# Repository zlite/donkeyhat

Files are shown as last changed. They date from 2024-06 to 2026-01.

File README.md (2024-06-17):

This is the repo for the new Donkeycar RC hat (aka Donkeyhat) for the Raspberry Pi. It has a Waveshare RP2040-zero microprocessor running CircuitPython 9.x and has the following functions:

* Read three channels of RC input from a standard RC receiver
* Control two servo channels (steering and throttle)
* Communicates with the RaspberryPi via hardware serial/UART
* Display data on an OLED screen (controlled by the Raspberry Pi via I2C)
* Reads two wheel/shaft encoders, and can handle both single channel and quadrature encoders
* Blinks a Neopixel LED to show normal operation

Instructructions:
* Copy the CircuitPython firmware to the RP2040 following these instructions: https://circuitpython.org/board/waveshare_rp2040_zero/
* Copy the required Neopixel library files to the "lib" directory of your RP2040 as instructed here: https://learn.adafruit.com/circuitpython-essentials/circuitpython-neopixel
* Copy the `code.py` file to the root for the RP2040 (CircuitPython always runs code.py at startup)
* Use the Mu Editor for modifying the code: https://codewith.mu/

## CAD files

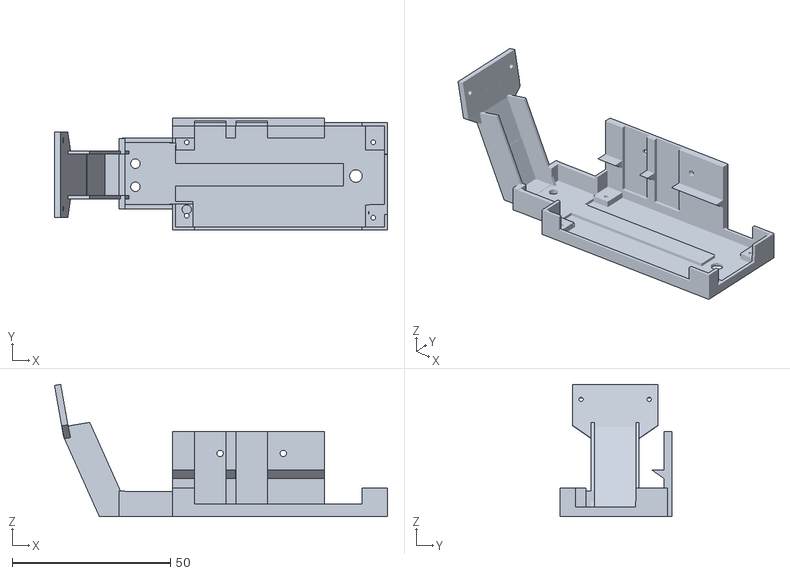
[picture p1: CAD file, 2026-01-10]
Mini RC hat mount.stl
105.4 x 35.5 x 41.8

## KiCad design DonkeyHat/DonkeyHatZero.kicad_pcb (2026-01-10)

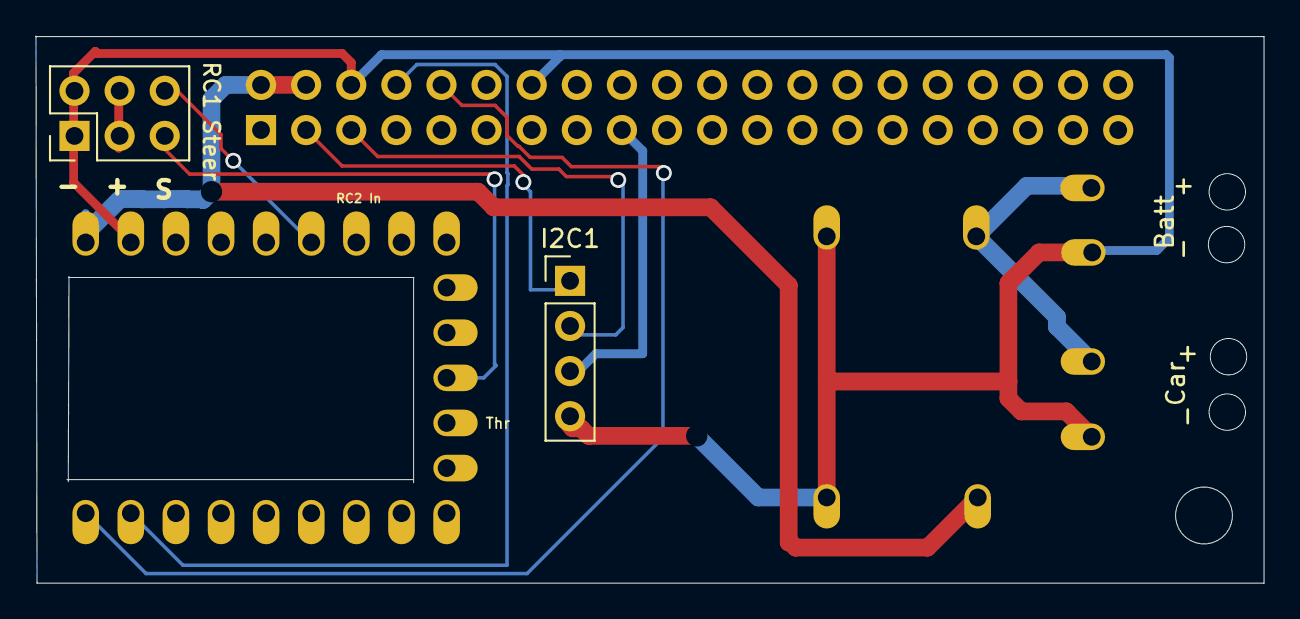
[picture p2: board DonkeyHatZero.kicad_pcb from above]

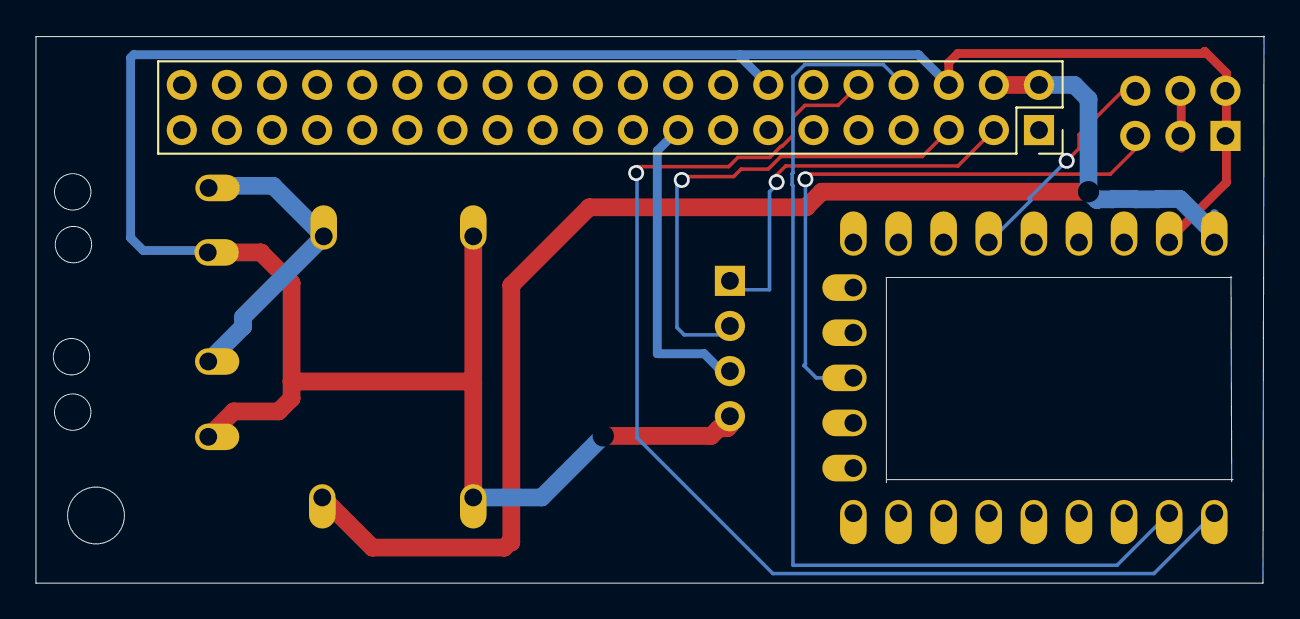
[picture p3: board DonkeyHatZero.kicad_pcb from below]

Board: 2 copper layers, 69.1 x 30.8 mm, 4 parts (2 on the bottom side), 10 nets.

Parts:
I2C1: Conn_01x04_Pin; PinHeader_1x04_P2.54mm_Vertical
J1: GPIO; PinSocket_2x20_P2.54mm_Vertical
J4: Conn_02x03_Top_Bottom; PinHeader_2x03_P2.54mm_Vertical
U2: rp2040-zero; rp2040-zero-tht

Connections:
+3V3: I2C1.3, J1.1, J1.17
+5V: J1.2, J1.4, U2.23 (5V)
/GPIO2/SDA1: I2C1.1, J1.3
/GPIO3/SCL1: I2C1.2, J1.5
GND: I2C1.4, J1.6, J1.14, J4.1, J4.4, U2.22 (GND)
unnamed: J4.2, J4.5
RCin1: J4.6, U2.18 (27)
Rpi Rx: J1.10, U2.1 (0)
Rpi Tx: J1.8, U2.2 (1)
Steer: J4.3, U2.12 (11)

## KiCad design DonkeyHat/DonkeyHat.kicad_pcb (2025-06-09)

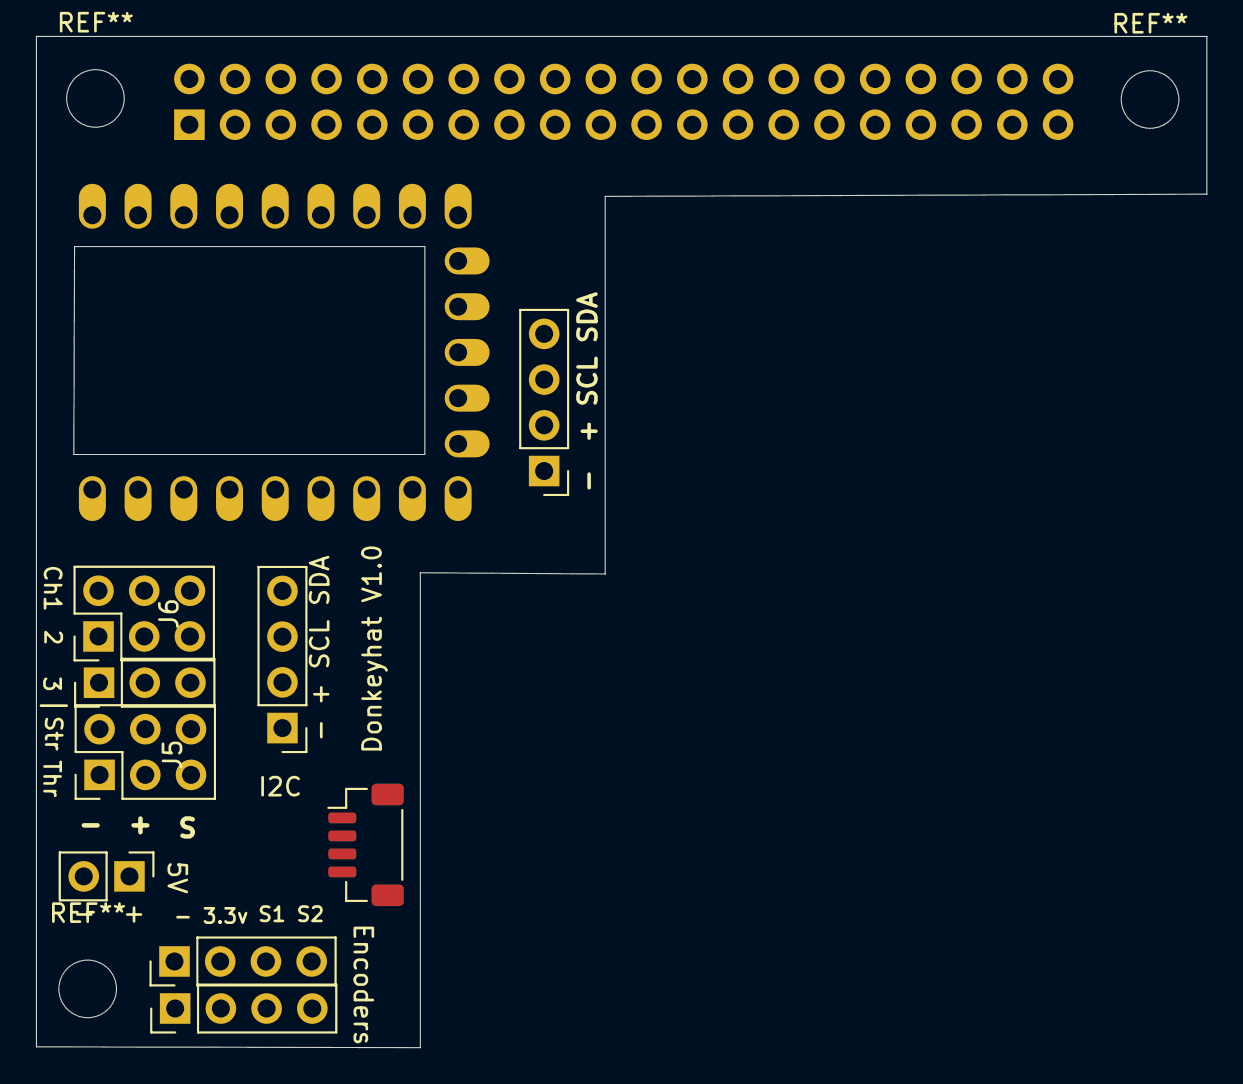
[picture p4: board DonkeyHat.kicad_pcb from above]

Board: 2 copper layers, 65.0 x 56.2 mm, 11 parts (1 on the bottom side), 17 nets, no tracks yet.

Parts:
5V1: Conn_01x02_Pin; PinHeader_1x02_P2.54mm_Vertical
I2C1: Conn_01x04_Pin; PinHeader_1x04_P2.54mm_Vertical
J1: GPIO; PinSocket_2x20_P2.54mm_Vertical
J2: Encoder 2; PinHeader_1x04_P2.54mm_Vertical
J3: Encoder 1; PinHeader_1x04_P2.54mm_Vertical
J4: I2C; JST_SH_BM04B-SRSS-TB_1x04-1MP_P1.00mm_Vertical
J5, J6: Conn_02x03_Odd_Even; PinHeader_2x03_P2.54mm_Vertical
OLED1: Conn_01x04_Pin; PinHeader_1x04_P2.54mm_Vertical
Throttle1: Conn_01x03_Pin; PinHeader_1x03_P2.54mm_Vertical
U2: rp2040-zero; rp2040-zero-tht

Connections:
+3V3: I2C1.2, J1.1, J1.17, J2.2, J3.2, J4.3, OLED1.2
+5V: 5V1.1, J1.2, J1.4, J6.3, J6.4, Throttle1.2, U2.23 (5V)
/GPIO2/SDA1: I2C1.4, J1.3, J4.2, OLED1.4
/GPIO3/SCL1: I2C1.3, J1.5, J4.1, OLED1.3
Batt: J5.3, J5.4
Enc1A: J3.3, U2.8 (7)
Enc1B: J3.4, U2.9 (8)
Enc2A: J2.3, U2.13 (12)
Enc2B: J2.4, U2.14 (13)
GND: 5V1.2, I2C1.1, J1.6, J1.9, J1.14, J1.20, J1.25, J1.30, J1.34, J1.39, J2.1, J3.1, J4.4, J5.1, J5.2, J6.1, J6.2, OLED1.1, Throttle1.1, U2.22 (GND)
RCin1: J6.6, U2.18 (27)
RCin2: J6.5, U2.17 (26)
RCin3: Throttle1.3, U2.20 (29)
Rpi Rx: J1.10, U2.1 (0)
Rpi Tx: J1.8, U2.2 (1)
Steer: J5.6, U2.12 (11)
Throttle: J5.5, U2.11 (10)

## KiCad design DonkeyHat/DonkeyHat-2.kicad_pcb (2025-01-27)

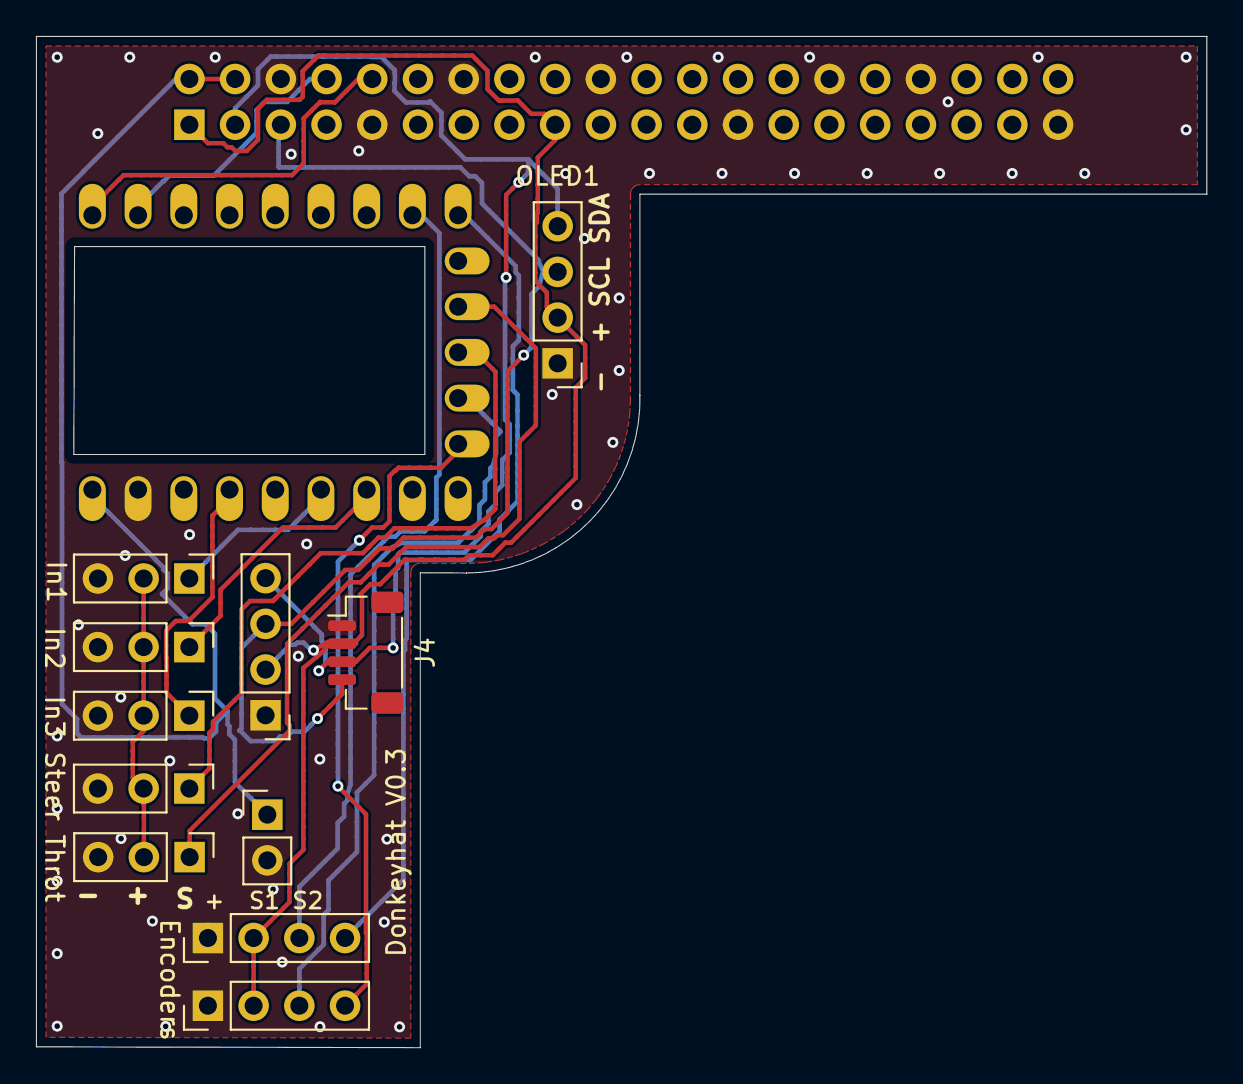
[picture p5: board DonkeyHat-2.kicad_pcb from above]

Board: 2 copper layers, 65.0 x 56.2 mm, 13 parts (1 on the bottom side), 17 nets.

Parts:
5V1: Conn_01x02_Pin; PinHeader_1x02_P2.54mm_Vertical
I2C1: Conn_01x04_Pin; PinHeader_1x04_P2.54mm_Vertical
In1: RC 1; PinHeader_1x03_P2.54mm_Vertical
In2, In3: Conn_01x03_Pin; PinHeader_1x03_P2.54mm_Vertical
J1: GPIO; PinSocket_2x20_P2.54mm_Vertical
J2: Encoder 2; PinHeader_1x04_P2.54mm_Vertical
J3: Encoder 1; PinHeader_1x04_P2.54mm_Vertical
J4: B4B-PH-K-S_LF__SN_; JST_SH_BM04B-SRSS-TB_1x04-1MP_P1.00mm_Vertical
OLED1: Conn_01x04_Pin; PinHeader_1x04_P2.54mm_Vertical
St1: Conn_01x03_Pin; PinHeader_1x03_P2.54mm_Vertical
Thr1: Conn_01x03_Pin; PinHeader_1x03_P2.54mm_Vertical
U2: rp2040-zero; rp2040-zero-tht

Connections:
+3V3: I2C1.2, J1.1, J1.17, J2.2, J3.2, J4.2, OLED1.2
+5V: 5V1.1, J1.2, J1.4, U2.23 (5V)
+BATT: In1.2, In2.2, In3.2, St1.2, Thr1.2
/GPIO2/SDA1: I2C1.4, J1.3, J4.3, OLED1.4
/GPIO3/SCL1: I2C1.3, J1.5, J4.4, OLED1.3
/GPIO14/TXD0: J1.8, U2.2 (1)
/GPIO15/RXD0: J1.10, U2.1 (0)
Enc1A: J3.3, U2.8 (7)
Enc1B: J3.4, U2.9 (8)
Enc2A: J2.3, U2.13 (12)
Enc2B: J2.4, U2.14 (13)
GND: 5V1.2, I2C1.1, In1.3, In2.3, In3.3, J1.6, J1.9, J1.14, J1.20, J1.25, J1.30, J1.34, J1.39, J2.1, J3.1, J4.1, OLED1.1, St1.3, Thr1.3, U2.22 (GND)
unnamed: In1.1, U2.20 (29)
unnamed: In2.1, U2.17 (26)
unnamed: In3.1, U2.18 (27)
unnamed: St1.1, U2.11 (10)
unnamed: Thr1.1, U2.12 (11)

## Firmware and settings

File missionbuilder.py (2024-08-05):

import sys
import csv
import os
import math
import json
from PySide6.QtWidgets import QApplication, QMainWindow, QVBoxLayout, QHBoxLayout, QWidget, QPushButton, QListWidget, QListWidgetItem, QDoubleSpinBox, QLabel, QFileDialog, QCheckBox, QMessageBox
from PySide6.QtWebEngineWidgets import QWebEngineView
from PySide6.QtWebEngineCore import QWebEnginePage, QWebEngineProfile, QWebEngineSettings
from PySide6.QtCore import QUrl, QObject, Slot, Qt
from PySide6.QtWebChannel import QWebChannel
from PySide6.QtCore import QTimer

class CustomWebEnginePage(QWebEnginePage):
    def javaScriptConsoleMessage(self, level, message, lineNumber, sourceID):
        print(f"JS Console ({level}): {message} [line {lineNumber}]")

class Bridge(QObject):
    @Slot(float, float)
    def addWaypoint(self, lat, lng):
        window.add_waypoint(lat, lng, is_relative=window.relative_checkbox.isChecked())

    @Slot(int, float, float)
    def updateWaypoint(self, index, lat, lng):
        window.update_waypoint(index, lat, lng)

class WaypointWidget(QWidget):
    def __init__(self, number, lat, lng, throttle=0.2, parent=None):
        super().__init__(parent)
        self.layout = QHBoxLayout(self)
        self.layout.setContentsMargins(0, 0, 0, 0)
        self.number_label = QLabel(f"{number}.")
        self.coords_label = QLabel()
        self.throttle_spinbox = QDoubleSpinBox()
        self.throttle_spinbox.setRange(0, 1)
        self.throttle_spinbox.setSingleStep(0.1)
        self.throttle_spinbox.setValue(throttle)
        self.throttle_spinbox.setDecimals(2)
        self.throttle_spinbox.setFixedWidth(90)
        self.throttle_spinbox.setAlignment(Qt.AlignRight)

        self.layout.addWidget(self.number_label)
        self.layout.addWidget(self.coords_label, 1)
        self.layout.addWidget(QLabel("Throttle:"))
        self.layout.addWidget(self.throttle_spinbox)

        self.abs_lat = lat
        self.abs_lng = lng
        self.rel_lat = 0
        self.rel_lng = 0
        self.is_relative = False
        self.update_coords(lat, lng)

    def update_number(self, number):
        self.number_label.setText(f"{number}.")

    def update_coords(self, lat, lng, relative=False, home_lat=None, home_lng=None):
        self.is_relative = relative
        if relative and home_lat is not None and home_lng is not None:
            self.rel_lat = lat  # lat is already in meters
            self.rel_lng = lng  # lng is already in meters
            self.abs_lat, self.abs_lng = self.meters_to_lat_lon(lat, lng, home_lat, home_lng)
            self.coords_label.setText(f"ΔLat: {lat:.2f}m, ΔLng: {lng:.2f}m")
        else:
            self.abs_lat = lat
            self.abs_lng = lng
            self.rel_lat = 0
            self.rel_lng = 0
            self.coords_label.setText(f"Lat: {lat:.6f}, Lng: {lng:.6f}")

    @staticmethod
    def meters_to_lat_lon(dlat_m, dlng_m, home_lat, home_lng):
        dlat = dlat_m / 111139
        dlng = dlng_m / (111139 * math.cos(math.radians(home_lat)))
        return home_lat + dlat, home_lng + dlng

    def get_data(self):
        return {
            "abs_lat": self.abs_lat,
            "abs_lng": self.abs_lng,
            "rel_lat": self.rel_lat,
            "rel_lng": self.rel_lng,
            "is_relative": self.is_relative,
            "throttle": self.throttle_spinbox.value()
        }

class WaypointCreator(QMainWindow):
    def __init__(self):
        super().__init__()
        self.setWindowTitle("Donkeycar Waypoint Creator")
        self.setGeometry(100, 100, 1200, 600)

        main_layout = QHBoxLayout()

        self.map_widget = QWebEngineView()
        main_layout.addWidget(self.map_widget, 7)

        sidebar_layout = QVBoxLayout()
        
        self.waypoint_list = QListWidget()
        self.waypoint_list.setDragDropMode(QListWidget.InternalMove)
        self.waypoint_list.model().rowsMoved.connect(self.on_waypoints_reordered)
        sidebar_layout.addWidget(self.waypoint_list)

        delete_button = QPushButton("Delete Selected Waypoint")
        delete_button.clicked.connect(self.delete_selected_waypoint)
        sidebar_layout.addWidget(delete_button)

        save_button = QPushButton("Save Waypoints")
        save_button.clicked.connect(self.save_waypoints)
        sidebar_layout.addWidget(save_button)

        load_button = QPushButton("Load Waypoints")
        load_button.clicked.connect(self.load_waypoints)
        sidebar_layout.addWidget(load_button)

        set_home_button = QPushButton("Set Home to Map Center")
        set_home_button.clicked.connect(self.set_home_to_map_center)
        sidebar_layout.addWidget(set_home_button)

        self.relative_checkbox = QCheckBox("Use Relative Coordinates")
        self.relative_checkbox.stateChanged.connect(self.toggle_relative_coordinates)
        sidebar_layout.addWidget(self.relative_checkbox)

        main_layout.addLayout(sidebar_layout, 3)

        central_widget = QWidget()
        central_widget.setLayout(main_layout)
        self.setCentralWidget(central_widget)

        self.init_map()
        self.home_lat = None
        self.home_lng = None
        self.waypoints = []
        self.is_relative = False

    def delay_init(self):
        QTimer.singleShot(1000, self.post_map_init)

    def post_map_init(self):
        # Any initialization that needs to happen after the map is loaded
        print("Map should be loaded now")
        # You can add any necessary initialization here

    def init_map(self):
        self.channel = QWebChannel()
        self.bridge = Bridge()
        self.channel.registerObject('bridge', self.bridge)

        profile = QWebEngineProfile.defaultProfile()
        settings = profile.settings()
        settings.setAttribute(QWebEngineSettings.LocalContentCanAccessRemoteUrls, True)
        settings.setAttribute(QWebEngineSettings.LocalContentCanAccessFileUrls, True)
        settings.setAttribute(QWebEngineSettings.AllowGeolocationOnInsecureOrigins, True)
        settings.setAttribute(QWebEngineSettings.AllowRunningInsecureContent, True)

        page = CustomWebEnginePage(profile, self.map_widget)
        page.setWebChannel(self.channel)

        page.featurePermissionRequested.connect(self.handlePermissionRequest)

        self.map_widget.setPage(page)

        html_path = os.path.join(os.path.dirname(os.path.abspath(__file__)), "map_template.html")
        self.map_widget.setUrl(QUrl.fromLocalFile(html_path))
 
    def meters_to_lat_lon(self, dlat_m, dlng_m, home_lat, home_lng):
        dlat = dlat_m / 111139
        dlng = dlng_m / (111139 * math.cos(math.radians(home_lat)))
        return home_lat + dlat, home_lng + dlng

    def lat_lon_to_meters(self, lat, lng, home_lat, home_lng):
        dlat_m = (lat - home_lat) * 111139
        dlng_m = (lng - home_lng) * 111139 * math.cos(math.radians(home_lat))
        return dlat_m, dlng_m

    def handlePermissionRequest(self, url, feature):
        if feature == QWebEnginePage.Geolocation:
            self.map_widget.page().setFeaturePermission(url, feature, QWebEnginePage.PermissionGrantedByUser)
        else:
            self.map_widget.page().setFeaturePermission(url, feature, QWebEnginePage.PermissionDeniedByUser)

    def add_waypoint(self, lat, lng, throttle=0.2, is_relative=False):
        if self.waypoint_list.count() == 0:
            self.home_lat, self.home_lng = lat, lng
            is_relative = False
        
        waypoint_widget = WaypointWidget(self.waypoint_list.count() + 1, lat, lng, throttle)
        
        if is_relative:
            rel_lat = (lat - self.home_lat) * 111139
            rel_lng = (lng - self.home_lng) * 111139 * math.cos(math.radians(self.home_lat))
            waypoint_widget.update_coords(rel_lat, rel_lng, relative=True, home_lat=self.home_lat, home_lng=self.home_lng)
        else:
            waypoint_widget.update_coords(lat, lng, relative=False)
        
        item = QListWidgetItem(self.waypoint_list)
        item.setSizeHint(waypoint_widget.sizeHint())
        self.waypoint_list.addItem(item)
        self.waypoint_list.setItemWidget(item, waypoint_widget)
        
        self.update_map_markers()

    def update_waypoint(self, index, lat, lng):
        item = self.waypoint_list.item(index)
        waypoint_widget = self.waypoint_list.itemWidget(item)
        
        if index == 0:
            # First waypoint is always absolute
            waypoint_widget.update_coords(lat, lng, relative=False)
            self.home_lat, self.home_lng = lat, lng
        elif self.relative_checkbox.isChecked():
            # Convert the new absolute position to relative
            dlat_m, dlng_m = self.lat_lon_to_meters(lat, lng, self.home_lat, self.home_lng)
            waypoint_widget.update_coords(dlat_m, dlng_m, relative=True, home_lat=self.home_lat, home_lng=self.home_lng)
        else:
            waypoint_widget.update_coords(lat, lng, relative=False)
        
        self.update_waypoint_display()
        self.update_map_markers()
        print(f"Waypoint {index + 1} updated: Lat: {lat:.6f}, Lng: {lng:.6f}")

    def on_waypoints_reordered(self):
        for i in range(self.waypoint_list.count()):
            item = self.waypoint_list.item(i)
            waypoint_widget = self.waypoint_list.itemWidget(item)
            waypoint_widget.update_number(i + 1)
        self.update_map_markers()

    def delete_selected_waypoint(self):
        selected_items = self.waypoint_list.selectedItems()
        if selected_items:
            for item in selected_items:
                self.waypoint_list.takeItem(self.waypoint_list.row(item))
            self.on_waypoints_reordered()
            self.update_map_markers()

    def update_map_markers(self):
        waypoints = [self.waypoint_list.itemWidget(self.waypoint_list.item(i)).get_data() 
                    for i in range(self.waypoint_list.count())]
        map_waypoints = []
        for wp in waypoints:
            map_waypoints.append({
                "lat": wp['abs_lat'],
                "lng": wp['abs_lng'],
                "throttle": float(wp['throttle'])
            })
        self.map_widget.page().runJavaScript(f"updateMarkers({json.dumps(map_waypoints)});")

    def save_waypoints(self):
        options = QFileDialog.Options()
        options |= QFileDialog.DontUseNativeDialog
        file_name, _ = QFileDialog.getSaveFileName(self, "Save Waypoints", "donkey_path.csv", "CSV Files (*.csv)", options=options)
        if file_name:
            waypoints = [self.waypoint_list.itemWidget(self.waypoint_list.item(i)).get_data() 
                        for i in range(self.waypoint_list.count())]
            with open(file_name, 'w', newline='') as f:
                writer = csv.writer(f)
                for i, wp in enumerate(waypoints):
                    if i == 0 or not self.relative_checkbox.isChecked():
                        # Absolute coordinates: 10 decimal places
                        lat = f"{wp['abs_lat']:.10f}"
                        lng = f"{wp['abs_lng']:.10f}"
                    else:
                        # Relative coordinates: 2 decimal places
                        lat = f"{wp['rel_lat']:.2f}"
                        lng = f"{wp['rel_lng']:.2f}"
                    writer.writerow([lat, lng, f"{wp['throttle']:.2f}"])
            print(f"Waypoints saved to {file_name}")

    def load_waypoints(self):
        options = QFileDialog.Options()
        options |= QFileDialog.DontUseNativeDialog
        file_name, _ = QFileDialog.getOpenFileName(self, "Load Waypoints", "", "CSV Files (*.csv)", options=options)
        if file_name:
            self.waypoint_list.clear()
            self.home_lat = None
            self.home_lng = None
            
            self.waypoints = []
            self.is_relative = False
            with open(file_name, 'r') as f:
                reader = csv.reader(f)
                for i, row in enumerate(reader):
                    if len(row) == 3:
                        lat, lng, throttle = row
                        if i == 0:
                            # First waypoint is always absolute
                            lat, lng = float(lat), float(lng)
                            self.home_lat, self.home_lng = lat, lng
                        elif '.' in lat and len(lat.split('.')[1]) <= 2:
                            # Relative coordinates have 2 or fewer decimal places
                            self.is_relative = True
                            lat, lng = float(lat), float(lng)
                        else:
                            # Absolute coordinates
                            lat, lng = float(lat), float(lng)
                        throttle = float(throttle)
                        self.waypoints.append((lat, lng, throttle))
            
            self.relative_checkbox.setChecked(self.is_relative)
            self.process_waypoints()
    def set_home_to_map_center(self):
        js_code = """
        (function() {
            var map = getOrInitMap();
            if (map) {
                var center = map.getCenter();
                return JSON.stringify({
                    lat: center.lat,
                    lng: center.lng
                });
            } else {
                console.error("Map not initialized");
                return null;
            }
        })();
        """
        self.map_widget.page().runJavaScript(js_code, 0, self.on_map_center_received)
        print("Requested map center")

    def force_map_center_update(self):
        js_code = "storeMapCenter();"
        self.map_widget.page().runJavaScript(js_code)

    def on_map_center_received(self, result):
        print(f"Received result: {result}")
        try:
            if not result:
                raise ValueError("Received empty result from JavaScript")

            center = json.loads(result)

            if 'lat' not in center or 'lng' not in center:
                raise KeyError(f"Expected 'lat' and 'lng' keys, but got: {center.keys()}")

            new_home_lat, new_home_lng = float(center['lat']), float(center['lng'])
            print(f"New home set to: Lat: {new_home_lat:.6f}, Lng: {new_home_lng:.6f}")
            
            self.set_home_and_redraw_waypoints(new_home_lat, new_home_lng)
                
        except json.JSONDecodeError as e:
            print(f"Error decoding JSON: {e}")
        except KeyError as e:
            print(f"Error accessing data: {e}")
        except ValueError as e:
            print(f"Value error: {e}")
        except Exception as e:
            print(f"Unexpected error: {e}")
        finally:
            print(f"Raw received data: {result}")

    def on_map_center_received_fallback(self, result):
        print(f"Fallback received result: {result}")
        try:
            center = json.loads(result)
            new_home_lat, new_home_lng = float(center['lat']), float(center['lng'])
            print(f"New home set to: Lat: {new_home_lat:.6f}, Lng: {new_home_lng:.6f}")
            self.set_home_and_redraw_waypoints(new_home_lat, new_home_lng)
        except Exception as e:
            print(f"Error in fallback method: {e}")

    def set_home_and_redraw_waypoints(self, new_home_lat, new_home_lng):
        if self.waypoint_list.count() == 0:
            return

        old_home_lat, old_home_lng = self.home_lat, self.home_lng
        self.home_lat, self.home_lng = new_home_lat, new_home_lng

        # Update the first waypoint (home)
        first_item = self.waypoint_list.item(0)
        first_waypoint = self.waypoint_list.itemWidget(first_item)
        first_waypoint.update_coords(new_home_lat, new_home_lng, relative=False)

        # Update all other waypoints
        for i in range(1, self.waypoint_list.count()):
            item = self.waypoint_list.item(i)
            waypoint_widget = self.waypoint_list.itemWidget(item)
            data = waypoint_widget.get_data()
            
            if self.relative_checkbox.isChecked():
                # Keep the relative offset
                waypoint_widget.update_coords(data['rel_lat'], data['rel_lng'], relative=True, home_lat=self.home_lat, home_lng=self.home_lng)
            else:
                # Adjust absolute position
                dlat = data['abs_lat'] - old_home_lat
                dlng = data['abs_lng'] - old_home_lng
                new_lat = new_home_lat + dlat
                new_lng = new_home_lng + dlng
                waypoint_widget.update_coords(new_lat, new_lng, relative=False)

        self.update_waypoint_display()
        self.update_map_markers()
        print(f"Waypoints redrawn with new home location: Lat: {self.home_lat:.6f}, Lng: {self.home_lng:.6f}")

    def process_waypoints(self):
        if not self.waypoints:
            return

        # Clear existing waypoints
        self.waypoint_list.clear()

        # Process the first waypoint (always absolute)
        first_wp = self.waypoints[0]
        self.add_waypoint(first_wp[0], first_wp[1], first_wp[2], is_relative=False)
        self.home_lat, self.home_lng = first_wp[0], first_wp[1]

        # Process the rest of the waypoints
        for lat, lng, throttle in self.waypoints[1:]:
            if self.is_relative:
                # Convert relative meters to absolute coordinates
                abs_lat = self.home_lat + lat / 111139
                abs_lng = self.home_lng + lng / (111139 * math.cos(math.radians(self.home_lat)))
                self.add_waypoint(abs_lat, abs_lng, throttle, is_relative=True)
            else:
                self.add_waypoint(lat, lng, throttle, is_relative=False)

        self.update_waypoint_display()

    def toggle_relative_coordinates(self):
        is_relative = self.relative_checkbox.isChecked()
        if self.waypoint_list.count() > 0:
            first_wp = self.waypoint_list.itemWidget(self.waypoint_list.item(0)).get_data()
            self.home_lat, self.home_lng = first_wp['abs_lat'], first_wp['abs_lng']

        for i in range(self.waypoint_list.count()):
            item = self.waypoint_list.item(i)
            waypoint_widget = self.waypoint_list.itemWidget(item)
            data = waypoint_widget.get_data()
            
            if i == 0:
                waypoint_widget.update_coords(data['abs_lat'], data['abs_lng'], relative=False)
            else:
                if is_relative:
                    dlat_m, dlng_m = self.lat_lon_to_meters(data['abs_lat'], data['abs_lng'], self.home_lat, self.home_lng)
                    waypoint_widget.update_coords(dlat_m, dlng_m, relative=True, home_lat=self.home_lat, home_lng=self.home_lng)
                else:
                    waypoint_widget.update_coords(data['abs_lat'], data['abs_lng'], relative=False)

        self.update_map_markers()
        print(f"Toggled to {'relative' if is_relative else 'absolute'} coordinates")

    def update_waypoint_display(self):
        relative = self.relative_checkbox.isChecked()
        for i in range(self.waypoint_list.count()):
            item = self.waypoint_list.item(i)
            waypoint_widget = self.waypoint_list.itemWidget(item)
            data = waypoint_widget.get_data()
            if i == 0:
                # First waypoint is always absolute
                waypoint_widget.update_coords(data['abs_lat'], data['abs_lng'], relative=False)
            elif relative:
                waypoint_widget.update_coords(data['rel_lat'], data['rel_lng'], relative=True, home_lat=self.home_lat, home_lng=self.home_lng)
            else:
                waypoint_widget.update_coords(data['abs_lat'], data['abs_lng'], relative=False)
        
        self.update_map_markers()

if __name__ == '__main__':
    app = QApplication(sys.argv)
    window = WaypointCreator()
    window.show()
    sys.exit(app.exec())
    

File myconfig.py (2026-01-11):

"""
CAR CONFIG

This file is read by your car application's manage.py script to change the car
performance.

EXAMPLE
-----------
import dk
cfg = dk.load_config(config_path='~/mycar/config.py')
print(cfg.CAMERA_RESOLUTION)
"""

import os

# ==============================================================================
# 1. HARDWARE CONFIGURATION & I/O
#    (Camera, Drive Train, Sensors, Pins, Display)
# ==============================================================================

# PATHS
CAR_PATH = PACKAGE_PATH = os.path.dirname(os.path.realpath(__file__))
# DATA_PATH = os.path.join(CAR_PATH, 'data')
# MODELS_PATH = os.path.join(CAR_PATH, 'models')

# ------------------------------------------------------------------------------
# CAMERA SETUP
# ------------------------------------------------------------------------------

# Select the camera type.
# 'PICAM': Raspberry Pi Camera (CSI)
# 'WEBCAM': USB Camera
# 'CVCAM': OpenCV Camera (often same as WEBCAM)
# 'CSIC': High-speed CSI camera (e.g. Arducam)
# 'D435': Intel Realsense D435
# 'OAKD': Luxonis OAK-D
# 'MOCK': Simulation/Testing or when using GPS path following
# CAMERA_TYPE = "PICAM"

# The resolution of the input image. Higher resolution needs more processing power.
# IMAGE_W = 160
# IMAGE_H = 120

# The depth of the image. 3 for RGB, 1 for Greyscale.
# IMAGE_DEPTH = 3

# The framerate of the camera. Should generally match DRIVE_LOOP_HZ.
# CAMERA_FRAMERATE = 20

# Flip the image vertically (useful if camera is mounted upside down).
CAMERA_VFLIP = True

# Flip the image horizontally.
# CAMERA_HFLIP = False

# Used for 'WEBCAM' and 'CVCAM' when there is more than one camera connected.
# CAMERA_INDEX = 0

# CSIC Camera: 0=None, 4=Flip Horizontal, 6=Flip Vertical.
# CSIC_CAM_GSTREAMER_FLIP_PARM = 0

# Convert Blue-Green-Red (OpenCV default) to Red-Green-Blue.
# BGR2RGB = False

# Intel Realsense D435 specific settings
# REALSENSE_D435_RGB = True       # True to capture RGB image
# REALSENSE_D435_DEPTH = True     # True to capture depth as image array
# REALSENSE_D435_IMU = False      # True to capture IMU data (D435i only)
# REALSENSE_D435_ID = None        # Serial number of camera or None for auto-detect

# OAK-D Camera specific settings
# OAKD_RGB = True       # True to capture RGB image
# OAKD_DEPTH = True     # True to capture depth as image array
# OAKD_ID = None        # Serial number of camera or None for auto-detect


# ------------------------------------------------------------------------------
# I2C & DISPLAY
# ------------------------------------------------------------------------------

# I2C address of the PCA9685 servo driver (standard is 0x40).
# PCA9685_I2C_ADDR = 0x40

# I2C bus number. None will auto-detect (usually 1 on Pi).
# PCA9685_I2C_BUSNUM = None

# Enable the SSD1306 OLED display (small screen on the car).
USE_SSD1306_128_32 = True

# OLED Rotation: 0 = normal, 1 = 90 deg, 2 = 180 deg, 3 = 270 deg.
# SSD1306_128_32_I2C_ROTATION = 0

# OLED Resolution: 1 = 128x32, 2 = 128x64.
SSD1306_RESOLUTION = 2


# ------------------------------------------------------------------------------
# INPUT DEVICES (JOYSTICK / CONTROLLER)
# ------------------------------------------------------------------------------

# If True, the joystick is enabled by default without needing '--js' flag.
# USE_JOYSTICK_AS_DEFAULT = True

# The maximum throttle output (0.0 to 1.0) allowed by the joystick.
# Useful for limiting speed for beginners.
# JOYSTICK_MAX_THROTTLE = 0.5

# Scalar for steering. 1.0 is normal. <1.0 is less sensitive.
# JOYSTICK_STEERING_SCALE = 1.0

# The "deadzone" where small joystick movements are ignored (0.0 to 1.0).
# JOYSTICK_DEADZONE = 0.01

# Set to -1.0 to flip forward/backward direction on the joystick.
# JOYSTICK_THROTTLE_DIR = -1.0

# The linux device file for the joystick.
# JOYSTICK_DEVICE_FILE = "/dev/input/js0"

# The type of controller being used.
# Options: 'ps3', 'ps4', 'xbox', 'nimbus', 'wiiu', 'F710', 'rc3', 'MM1 (use for RC Hat)', 'custom'
CONTROLLER_TYPE = 'MM1'

# Enable listening for remote joystick control over the network.
# USE_NETWORKED_JS = False
# NETWORK_JS_SERVER_IP = None


# ------------------------------------------------------------------------------
# DRIVE TRAIN CONFIGURATION
# ------------------------------------------------------------------------------

# Select the drive train type. This determines how the software talks to the motors.
# "PWM_STEERING_THROTTLE": Standard RC car (Servo + ESC)
# "MM1": RoboHat MM1 or RC Hat
# "SERVO_HBRIDGE_2PIN": Servo for steering, HBridge (2 pin) for motor
# "SERVO_HBRIDGE_3PIN": Servo for steering, HBridge (3 pin) for motor
# "DC_STEER_THROTTLE": DC Motor for steering, DC Motor for drive (L298N)
# "DC_TWO_WHEEL": Differential drive (tank style), 2 Pin HBridge
# "DC_TWO_WHEEL_L298N": Differential drive (tank style), 3 Pin HBridge
# "VESC": VESC Motor Controller
DRIVE_TRAIN_TYPE = "MM1"

# Configuration for PWM_STEERING_THROTTLE (Standard RC Car)
# Requires calibration using 'donkey calibrate'.
# PWM_STEERING_THROTTLE = {
# "PWM_STEERING_PIN": "PCA9685.1:40.1",   # Pin for steering servo
# "PWM_STEERING_SCALE": 1.0,              # PWM frequency compensation
# "PWM_STEERING_INVERTED": False,         # Invert steering direction
# "PWM_THROTTLE_PIN": "PCA9685.1:40.0",   # Pin for ESC (Throttle)
# "PWM_THROTTLE_SCALE": 1.0,              # PWM frequency compensation
# "PWM_THROTTLE_INVERTED": False,         # Invert throttle direction
# "STEERING_LEFT_PWM": 460,               # Calibrated value: Full Left
# "STEERING_RIGHT_PWM": 290,              # Calibrated value: Full Right
# "THROTTLE_FORWARD_PWM": 500,            # Calibrated value: Max Forward
# "THROTTLE_STOPPED_PWM": 370,            # Calibrated value: Stopped
# "THROTTLE_REVERSE_PWM": 220,            # Calibrated value: Max Reverse
# }

# Configuration for SERVO_HBRIDGE_2PIN
# SERVO_HBRIDGE_2PIN = {
# "FWD_DUTY_PIN": "RPI_GPIO.BOARD.18",  # Pin for Forward
# "BWD_DUTY_PIN": "RPI_GPIO.BOARD.16",  # Pin for Reverse
# "PWM_STEERING_PIN": "RPI_GPIO.BOARD.33", # Pin for Servo
# "PWM_STEERING_SCALE": 1.0,
# "PWM_STEERING_INVERTED": False,
# "STEERING_LEFT_PWM": 460,
# "STEERING_RIGHT_PWM": 290,
# }

# Configuration for SERVO_HBRIDGE_3PIN
# SERVO_HBRIDGE_3PIN = {
# "FWD_PIN": "RPI_GPIO.BOARD.18",   # Enable Forward
# "BWD_PIN": "RPI_GPIO.BOARD.16",   # Enable Reverse
# "DUTY_PIN": "RPI_GPIO.BOARD.35",  # Speed Control (PWM)
# "PWM_STEERING_PIN": "RPI_GPIO.BOARD.33",
# "PWM_STEERING_SCALE": 1.0,
# "PWM_STEERING_INVERTED": False,
# "STEERING_LEFT_PWM": 460,
# "STEERING_RIGHT_PWM": 290,
# }

# Configuration for DC_STEER_THROTTLE (Motor for steering, Motor for drive)
# DC_STEER_THROTTLE = {
# "LEFT_DUTY_PIN": "RPI_GPIO.BOARD.18",   # Steer Left
# "RIGHT_DUTY_PIN": "RPI_GPIO.BOARD.16",  # Steer Right
# "FWD_DUTY_PIN": "RPI_GPIO.BOARD.15",    # Drive Forward
# "BWD_DUTY_PIN": "RPI_GPIO.BOARD.13",    # Drive Reverse
# }
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

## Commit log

2024-04-23 First PCB commit
    [DonkeyHat.kicad_pcb, DonkeyHat.kicad_sch]
2024-04-24 Fixed board outline
    [DonkeyHat.kicad_pcb]
2024-05-05 Switched to smaller 2040
    [DonkeyHat.kicad_pcb]
2024-05-12 Added 4-bit encoders
    [DonkeyHat.kicad_pcb, DonkeyHat.kicad_sch]
2024-05-13 Switched encoders to RP2040
    [DonkeyHat.kicad_pcb, DonkeyHat.kicad_sch]
2024-05-24 production version
    [DonkeyHat.kicad_pcb]
2024-05-26 Updated pin assignments, added encoder
2024-06-17 catellated pins
    [DonkeyHat.kicad_pcb, DonkeyHat.kicad_sch]
2024-07-01 Updated for two encoders
2024-07-06 Updated to work with Donkey encoder standard
2024-07-07 Updated for quadrature encoders
2024-07-13 Deadband added
    [DonkeyHat.kicad_pcb]
2024-07-30 Switched to Google Maps for higher resolution
2024-07-31 Added features
    Added relative coordinates option, ability to read and write waypoint files, save dialog
    [donkey_path.csv]
2024-08-01 Now detects relative or absolute coordinates in saved files and displays correctly
    [missionbuilder.py]
2024-08-02 Now allows relative waypoints to be reset to current home
    [missionbuilder.py]
2024-08-04 Fixed some relative waypoint issues
    [donkey_path.csv]
2024-08-05 Simplified CSV file
    [donkey_path.csv]
2024-09-15 Fixed tab bug
    [donkey_path.csv]
2024-09-29 Fixed timeout switch back to RC mode
    [code.py]
2025-01-27 New PCB
    [DonkeyHat-2.kicad_pcb, DonkeyHat.kicad_pcb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]
2025-03-02 UI improvements
    [DonkeyHat.kicad_pcb]
2025-06-09 Battery power for servos
    [DonkeyHat.kicad_pcb, DonkeyHat.kicad_sch]
2025-08-04 first start on zero
    [DonkeyHatZero.kicad_pcb, DonkeyHatZero.kicad_sch]
2025-08-18 Zero WIP
    [DonkeyHatZero.kicad_pcb, DonkeyHatZero.kicad_sch]
2025-08-18 Ready for routing
    [DonkeyHatZero.kicad_pcb, DonkeyHatZero.kicad_sch]
2025-08-18 castellated pads
    [DonkeyHatZero.kicad_pcb]
2025-09-01 Fixed spacing
    [DonkeyHatZero.kicad_pcb, DonkeyHatZero.kicad_sch]
2025-10-12 Updated zero
    [DonkeyHatZero.kicad_pcb, DonkeyHatZero.kicad_sch]
2025-10-21 DFM tweaks
    [DonkeyHatZero.kicad_pcb]
2025-11-16 Added latest prod version
    [DonkeyHat-prod.kicad_pcb, DonkeyHatZero.kicad_pcb, DonkeyHatZero.kicad_sch]
2025-12-19 Fixed jitter
2025-12-20 reinstates blue LED flashing
2025-12-22 Restored encoder and reset functionality
    [code.py]
2026-01-01 Added OLED
    [DonkeyHatZero.kicad_pcb, DonkeyHatZero.kicad_sch]
2026-01-04 STL file of Pi Zero mount
    [Mini RC hat mount.stl]
2026-01-06 minor tweaks
    [Mini RC hat mount.stl]
